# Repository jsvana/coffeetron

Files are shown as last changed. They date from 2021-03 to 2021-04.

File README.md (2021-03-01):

# coffeetron - WIP

Arduino sketch to pour a shot of espresso in a [Gaggia Classic Pro](https://www.gaggia.com/manual-machines/new-classic/) to a specific weight.

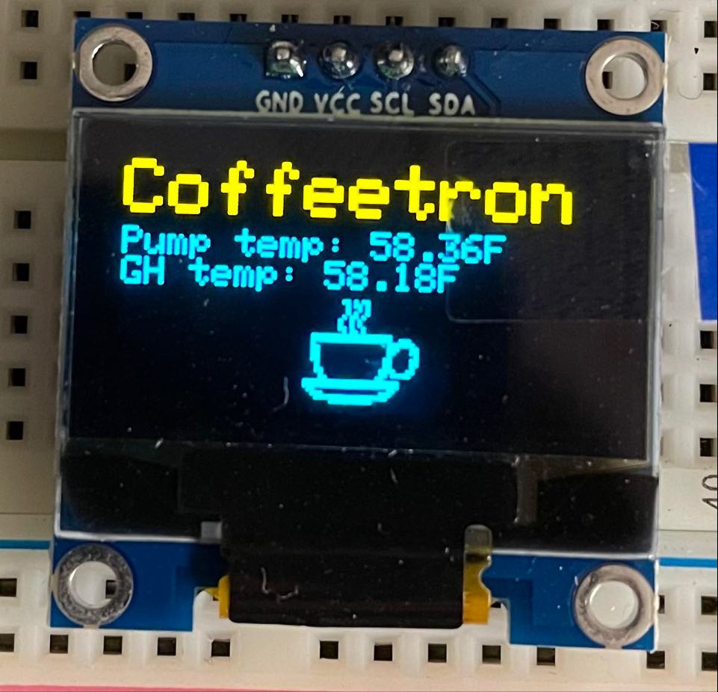
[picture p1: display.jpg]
Coffeetron display


Fun side project. Probably does things wrong, and isn't really useful unless you have the same setup I do. Feel free to use as a reference if you want!

## Pump control

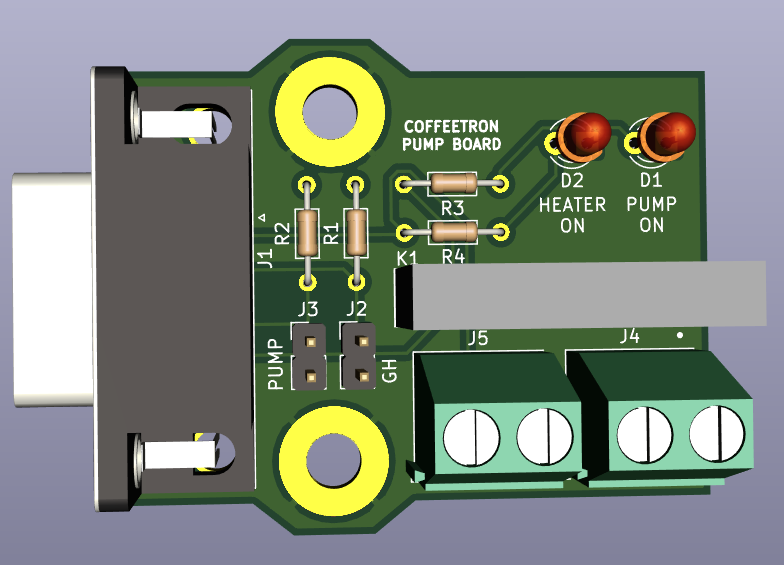
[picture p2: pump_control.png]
Pump control PCB


## License

[MIT](LICENSE.md)

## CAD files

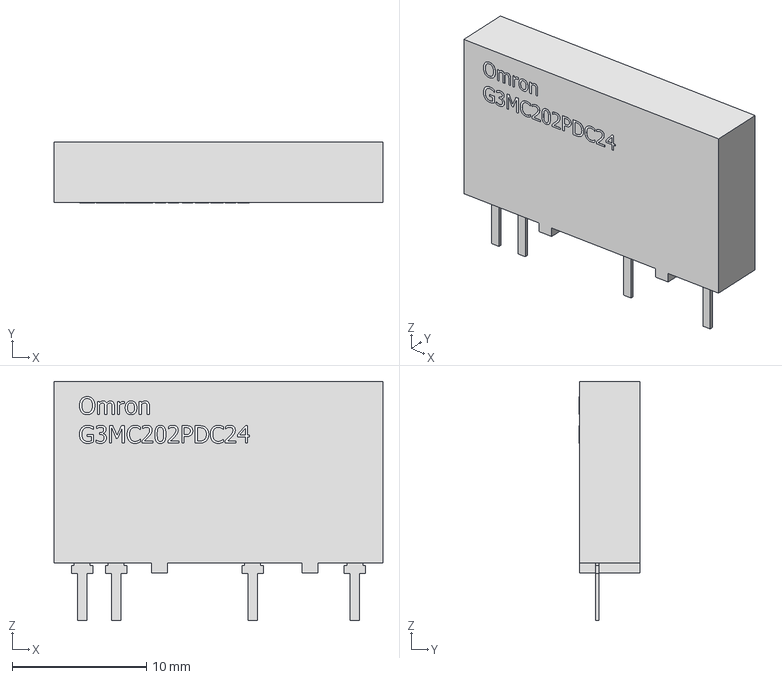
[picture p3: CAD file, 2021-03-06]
hardware/pump/eec.models/Omron_-_G3MC202PDC24.step
24.5 x 4.51 x 17.8 mm

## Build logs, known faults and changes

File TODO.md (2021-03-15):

# TODO

## Software
- [x] Flush
- [x] Preinfusion
- [ ] "Needs flush" warning after brew
- [x] Configurable targets
  - [x] Configurable output weight
  - [x] Configurable preinfusion enable
  - [x] Configurable preinfusion pump time
  - [x] Configurable preinfusion wait time
  - [x] Configurable brew temperature
  - [x] Minimum values on configuration selectors
- [ ] Stat output
- [ ] Fix screen corruption

## Head unit
- [x] Screen
- [x] Configurable value entry
- [x] Configurable entry selector button
- [x] Start button
- [x] Flush button
- [x] Brew stats button
- [ ] USB mount?
- [ ] On switch
- [ ] Reservoir level sensor
- [ ] Drip tray fill sensor
- [ ] PCB designed

## Pump controller
- [x] Grouphead temperature
- [x] Pump relay
- [x] Heater PID controller (~11A)
- [ ] Pump thermocouple
- [x] PCB designed

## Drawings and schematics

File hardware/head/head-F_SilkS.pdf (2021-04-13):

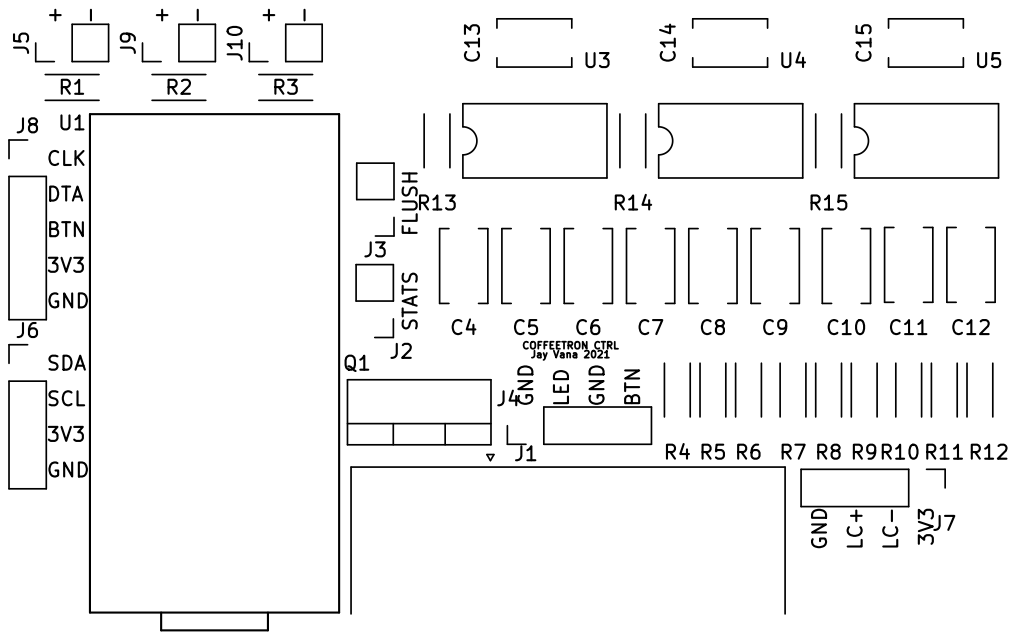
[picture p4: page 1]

- GND LED GND BTNSDA

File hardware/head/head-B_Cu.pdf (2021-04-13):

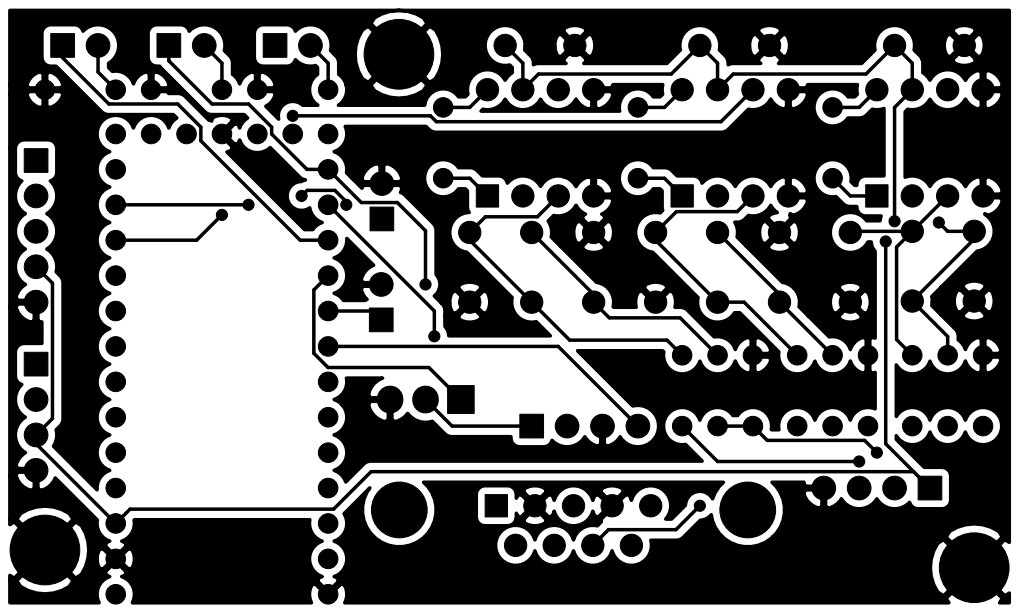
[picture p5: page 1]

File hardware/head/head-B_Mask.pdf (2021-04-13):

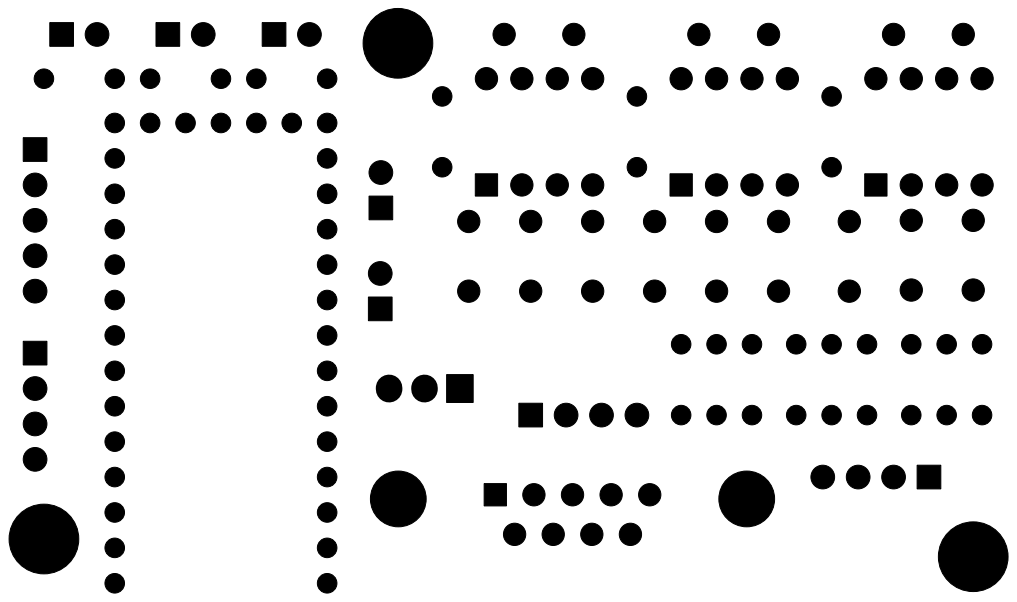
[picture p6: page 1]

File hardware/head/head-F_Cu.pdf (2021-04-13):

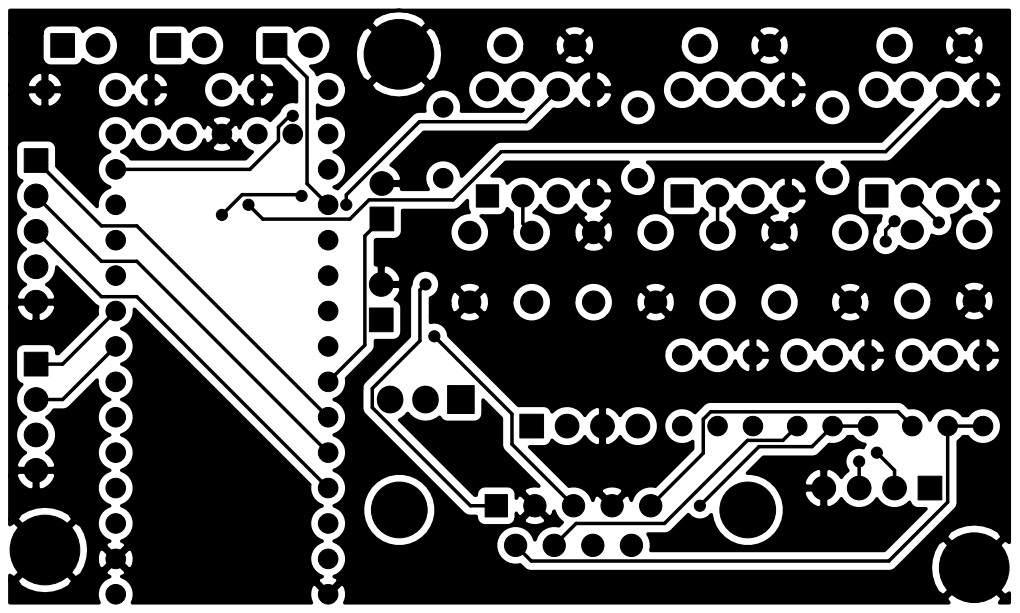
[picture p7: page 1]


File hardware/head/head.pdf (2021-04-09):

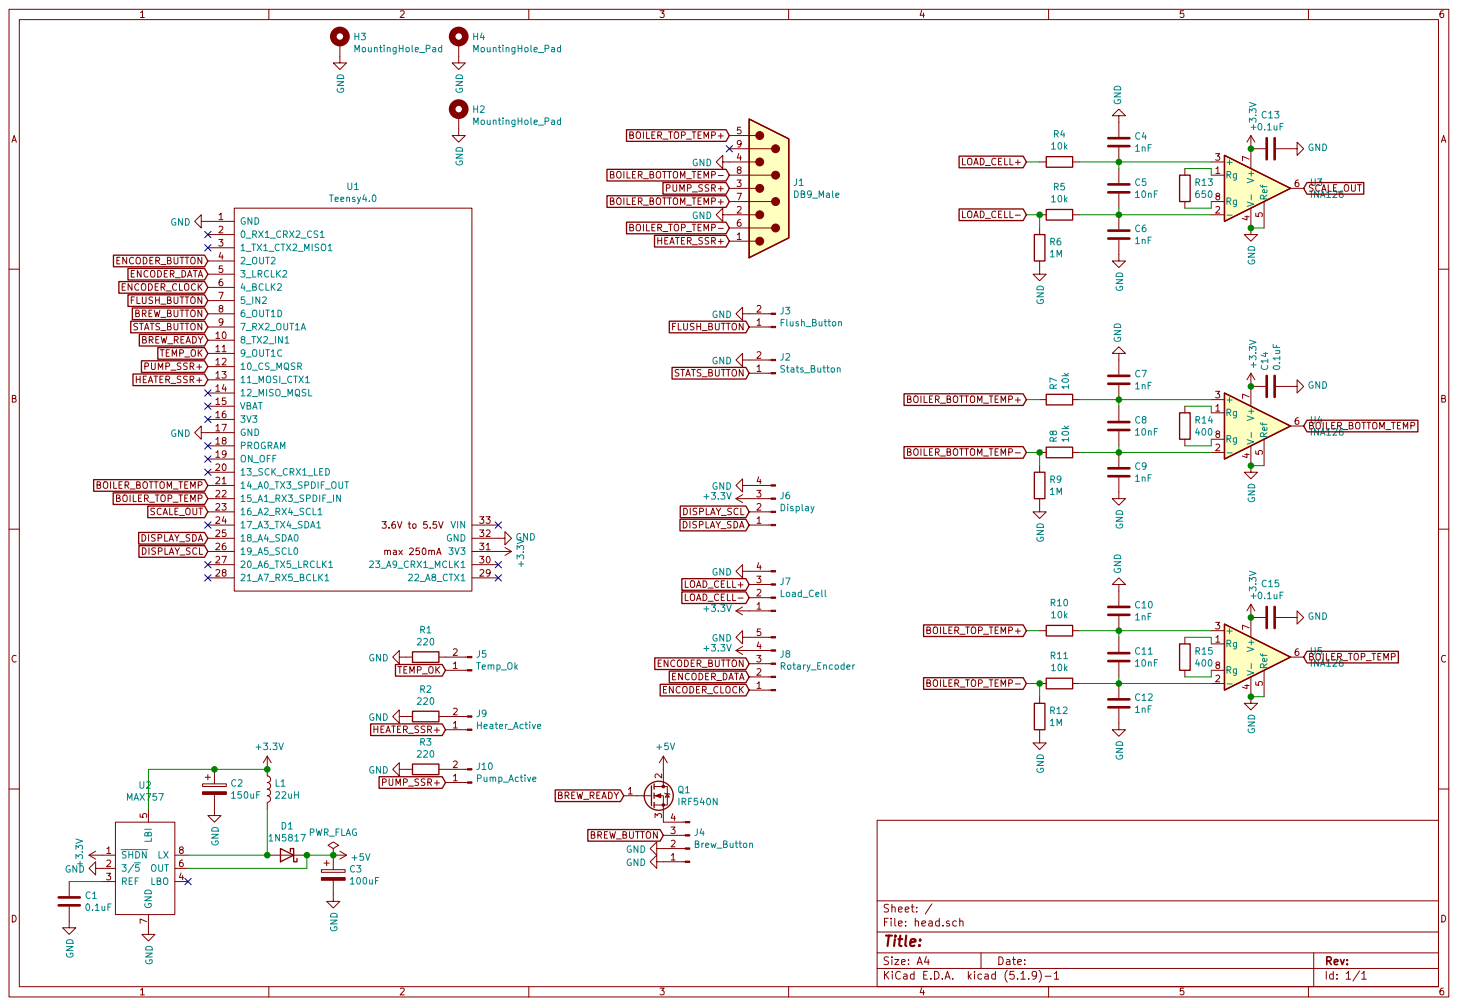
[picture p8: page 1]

Id: 1/1 Title: File: head.sch Sheet: /

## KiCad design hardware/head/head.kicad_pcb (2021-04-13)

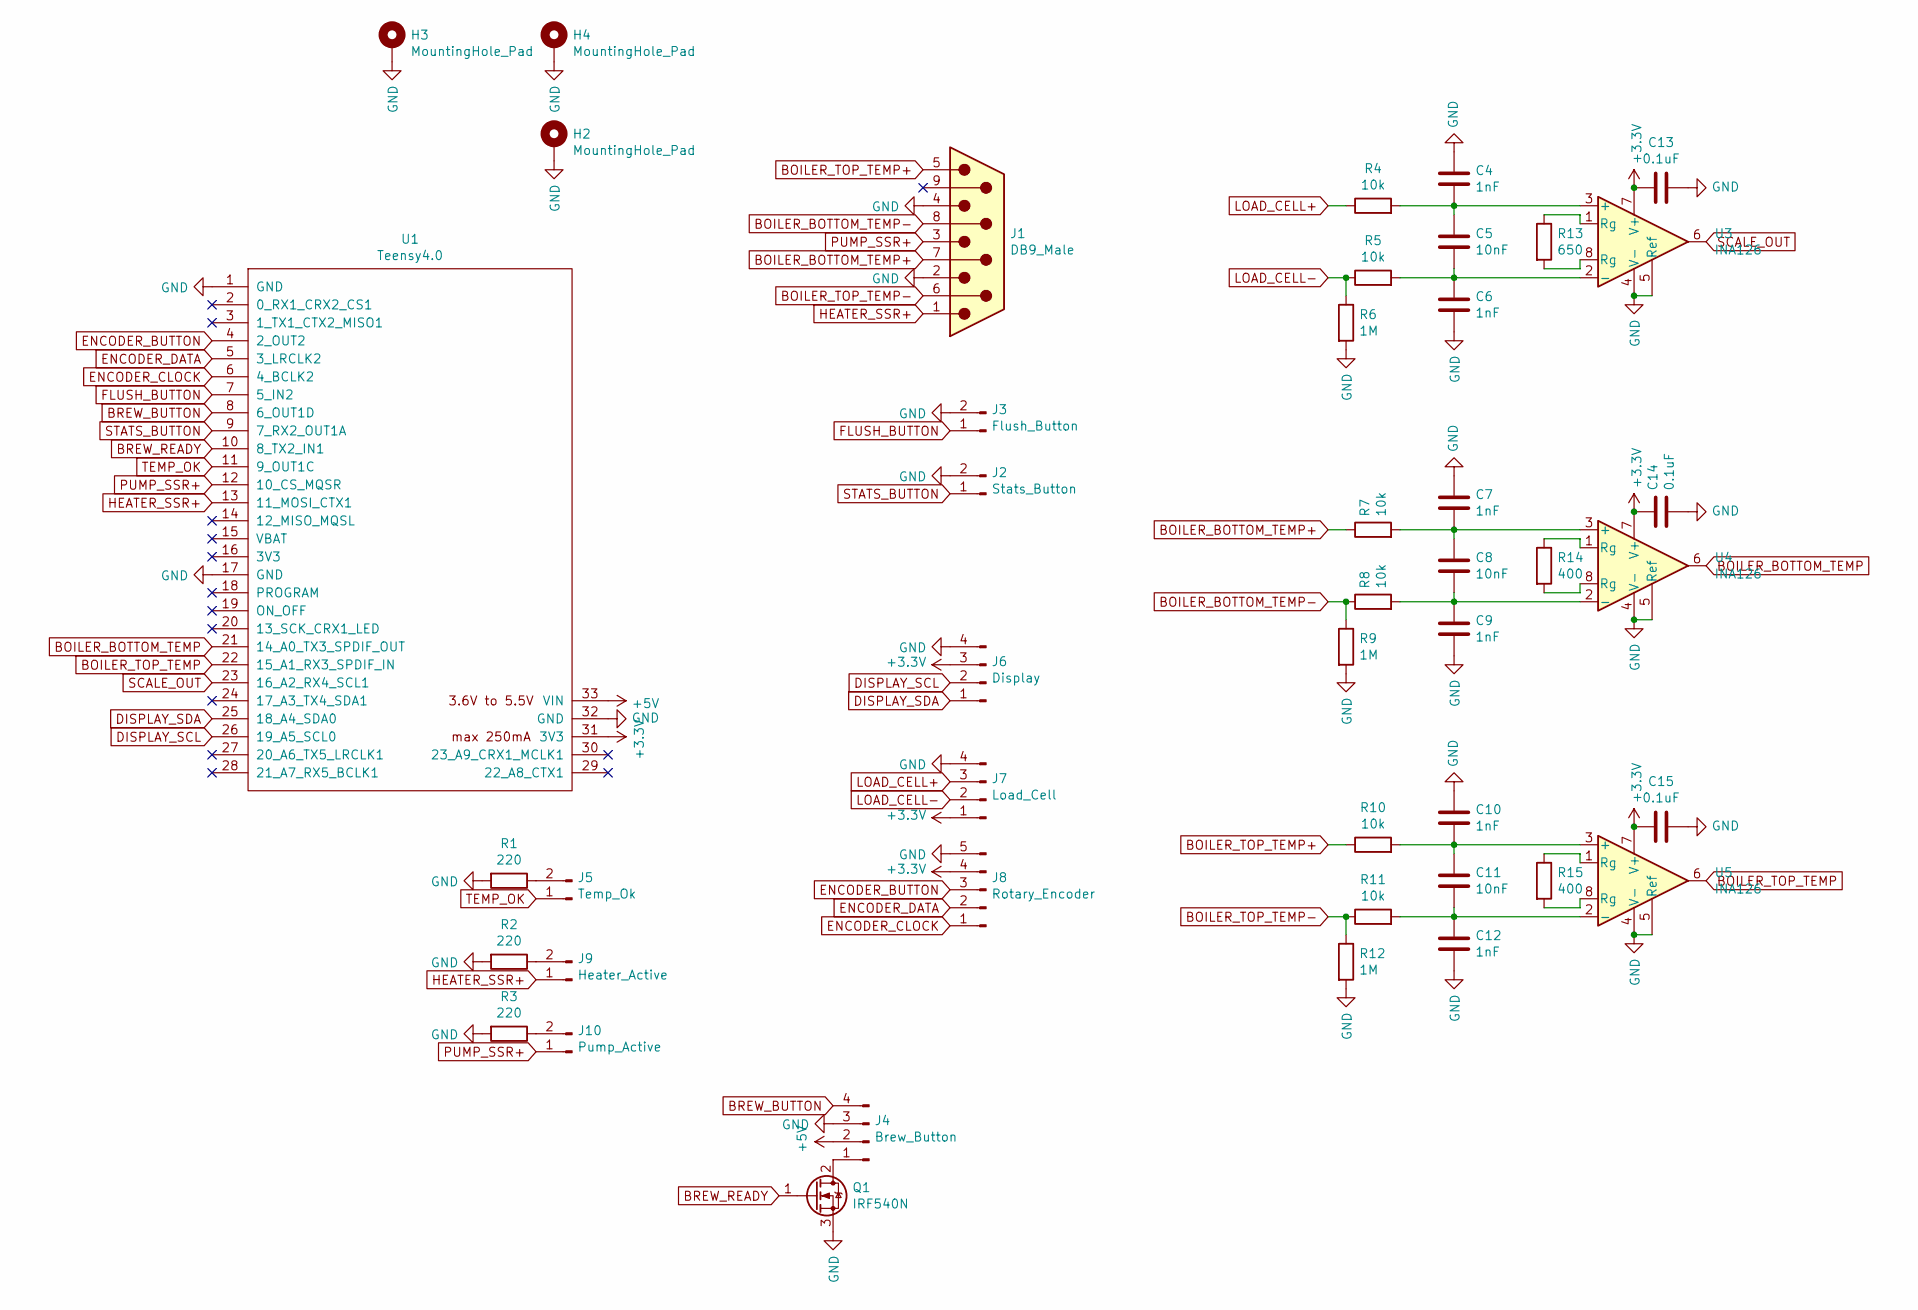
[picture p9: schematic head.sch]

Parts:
C4, C6, C7, C9, C10, C12: 1nF; C_Disc_D5.1mm_W3.2mm_P5.00mm
C5, C8, C11: 10nF; C_Disc_D5.1mm_W3.2mm_P5.00mm
C13, C14, C15: 0.1uF; C_Disc_D5.1mm_W3.2mm_P5.00mm
H2, H3, H4: MountingHole_Pad; MountingHole_2.5mm_Pad
J1: DB9_Male; DSUB-9_Male_Horizontal_P2.77x2.84mm_EdgePinOffset4.94mm_Hou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
J2: Stats_Button; PinHeader_1x02_P2.54mm_Vertical
J3: Flush_Button; PinHeader_1x02_P2.54mm_Vertical
J4: Brew_Button; PinHeader_1x04_P2.54mm_Vertical
J5: Temp_Ok; PinHeader_1x02_P2.54mm_Vertical
J6: Display; PinHeader_1x04_P2.54mm_Vertical
J7: Load_Cell; PinHeader_1x04_P2.54mm_Vertical
J8: Rotary_Encoder; PinHeader_1x05_P2.54mm_Vertical
J9: Heater_Active; PinHeader_1x02_P2.54mm_Vertical
J10: Pump_Active; PinHeader_1x02_P2.54mm_Vertical
Q1: IRF540N; TO-220-3_Vertical
R1, R2, R3: 220; R_Axial_DIN0204_L3.6mm_D1.6mm_P5.08mm_Horizontal
R4, R5, R7, R8, R10, R11: 10k; R_Axial_DIN0204_L3.6mm_D1.6mm_P5.08mm_Horizontal
R6, R9, R12: 1M; R_Axial_DIN0204_L3.6mm_D1.6mm_P5.08mm_Horizontal
R13: 650; R_Axial_DIN0204_L3.6mm_D1.6mm_P5.08mm_Horizontal
R14, R15: 400; R_Axial_DIN0204_L3.6mm_D1.6mm_P5.08mm_Horizontal
U1: Teensy4.0; Teensy40_SMT
U3, U4, U5: INA126; DIP-8_W7.62mm

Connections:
+3V3: C13.1, C14.1, C15.1, J6.3, J7.1, J8.4, U1.31 (3V3), U3.7 (V+), U4.7 (V+), U5.7 (V+)
+5V: J4.2, U1.33 (VIN)
BOILER_BOTTOM_TEMP: U1.21 (14_A0_TX3_SPDIF_OUT), U4.6
BOILER_BOTTOM_TEMP+: J1.7, R7.1
BOILER_BOTTOM_TEMP-: J1.8, R8.1, R9.1
BOILER_TOP_TEMP: U1.22 (15_A1_RX3_SPDIF_IN), U5.6
BOILER_TOP_TEMP+: J1.5, R10.1
BOILER_TOP_TEMP-: J1.6, R11.1, R12.1
BREW_BUTTON: J4.4, U1.8 (6_OUT1D)
BREW_READY: Q1.1 (G), U1.10 (8_TX2_IN1)
DISPLAY_SCL: J6.2, U1.26 (19_A5_SCL0)
DISPLAY_SDA: J6.1, U1.25 (18_A4_SDA0)
ENCODER_BUTTON: J8.3, U1.4 (2_OUT2)
ENCODER_CLOCK: J8.1, U1.6 (4_BCLK2)
ENCODER_DATA: J8.2, U1.5 (3_LRCLK2)
FLUSH_BUTTON: J3.1, U1.7 (5_IN2)
GND: C4.1, C6.2, C7.1, C9.2, C10.1, C12.2, C13.2, C14.2, C15.2, H2.1, H3.1, H4.1, J1.2, J1.4, J2.2, J3.2, J4.3, J6.4, J7.4, J8.5, Q1.3 (S), R1.2, R2.2, R3.2, R6.2, R9.2, R12.2, U1.1 (GND), U1.17 (GND), U1.32 (GND), U3.4 (V-), U3.5 (Ref), U4.4 (V-), U4.5 (Ref), U5.4 (V-), U5.5 (Ref)
HEATER_SSR+: J1.1, J9.1, U1.13 (11_MOSI_CTX1)
LOAD_CELL+: J7.3, R4.1
LOAD_CELL-: J7.2, R5.1, R6.1
unnamed: C4.2, C5.1, R4.2, U3.3 (+)
unnamed: C5.2, C6.1, R5.2, U3.2 (-)
unnamed: C7.2, C8.1, R7.2, U4.3 (+)
unnamed: C8.2, C9.1, R8.2, U4.2 (-)
unnamed: C10.2, C11.1, R10.2, U5.3 (+)
unnamed: C11.2, C12.1, R11.2, U5.2 (-)
unnamed: J4.1, Q1.2 (D)
unnamed: J5.2, R1.1
unnamed: J9.2, R2.1
unnamed: J10.2, R3.1
unnamed: R13.1, U3.1 (Rg)
unnamed: R13.2, U3.8 (Rg)
unnamed: R14.1, U4.1 (Rg)
unnamed: R14.2, U4.8 (Rg)
unnamed: R15.1, U5.1 (Rg)
unnamed: R15.2, U5.8 (Rg)
PUMP_SSR+: J1.3, J10.1, U1.12 (10_CS_MQSR)
SCALE_OUT: U1.23 (16_A2_RX4_SCL1), U3.6
STATS_BUTTON: J2.1, U1.9 (7_RX2_OUT1A)
TEMP_OK: J5.1, U1.11 (9_OUT1C)

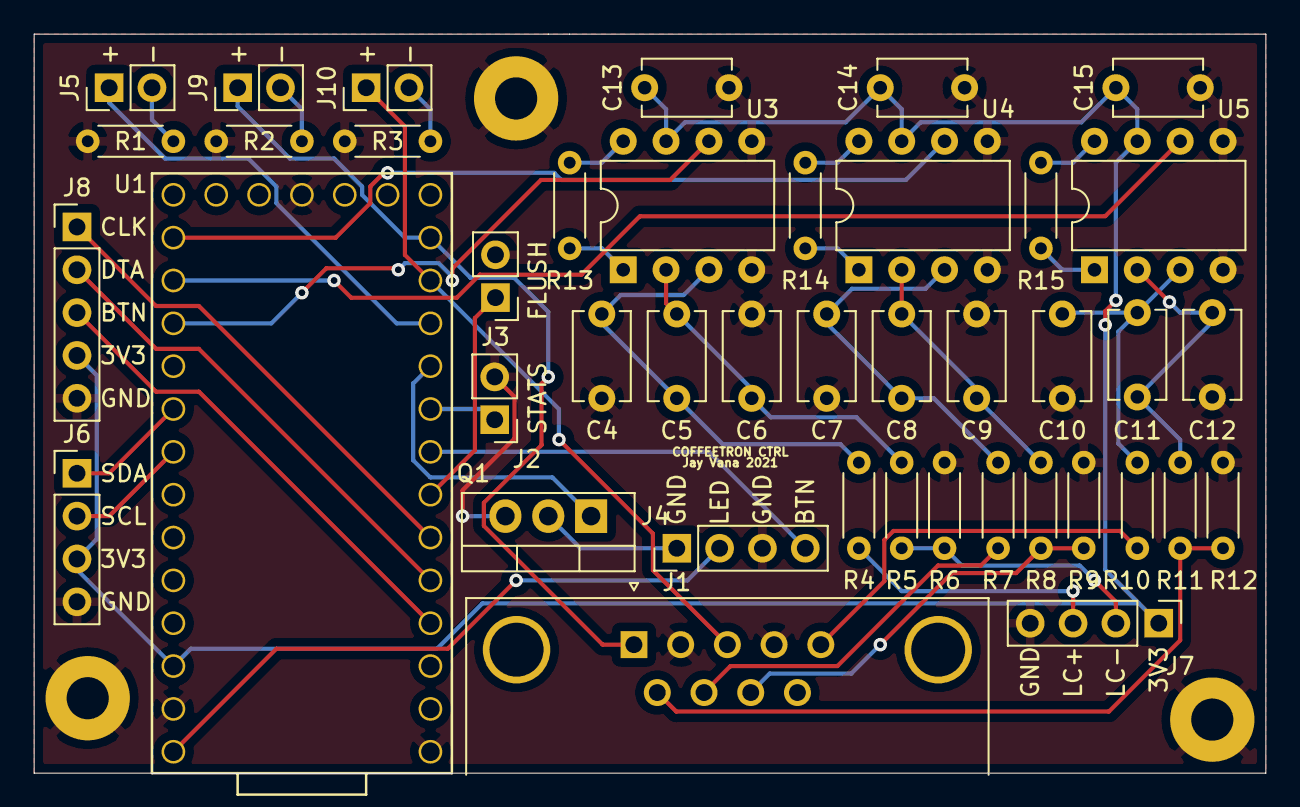
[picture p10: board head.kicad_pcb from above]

Board: 2 copper layers, 73.0 x 43.8 mm, 45 parts (0 on the bottom side), 40 nets.

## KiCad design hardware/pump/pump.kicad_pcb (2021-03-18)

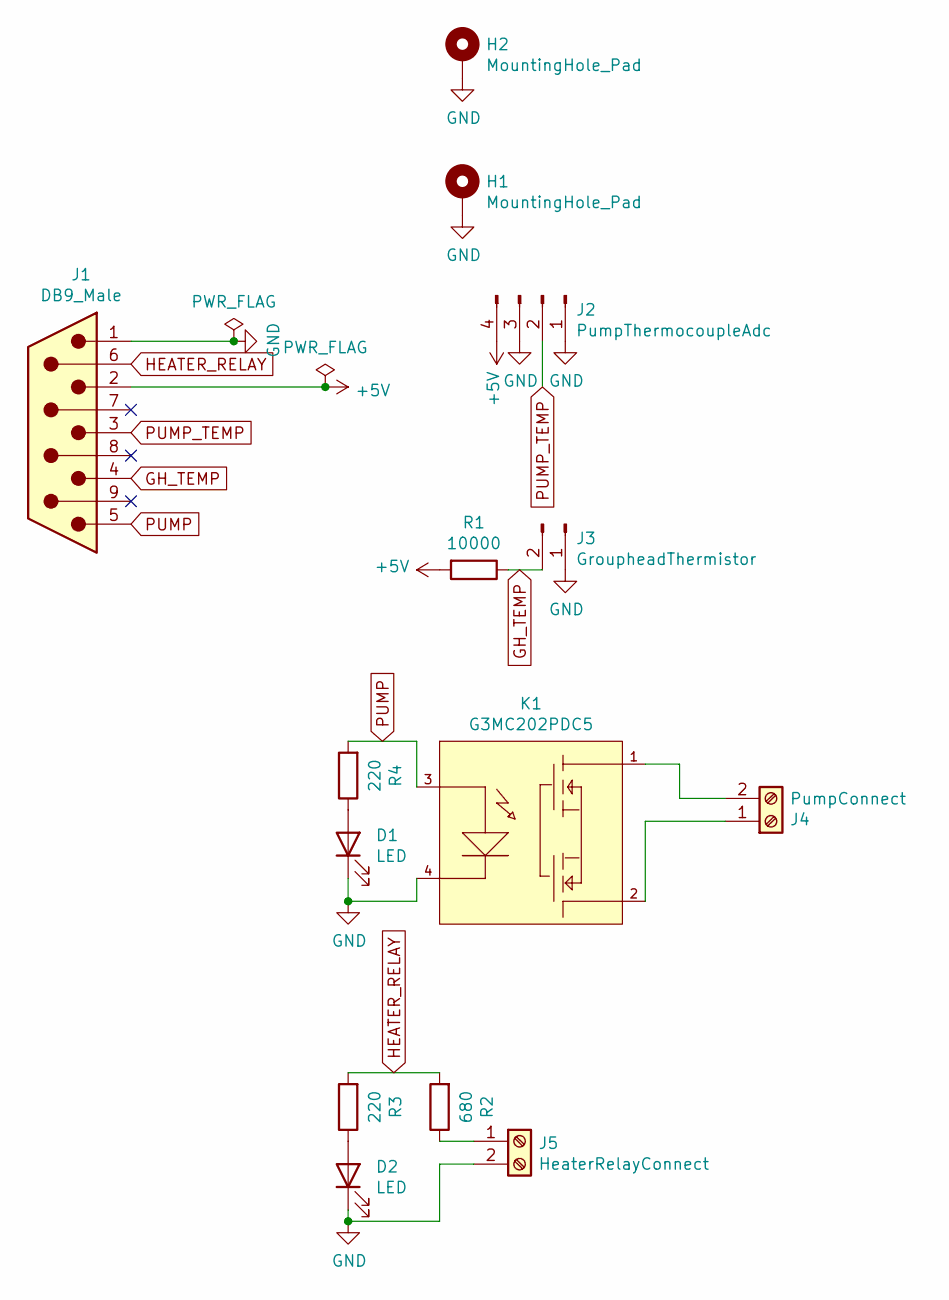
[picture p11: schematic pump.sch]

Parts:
D1, D2: LED; LED_D3.0mm
H1, H2: MountingHole_Pad; MountingHole_4.3mm_M4_Pad
J1: DB9_Male; DSUB-9_Male_Horizontal_P2.77x2.84mm_EdgePinOffset4.94mm_Hou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
J2: PumpThermocoupleAdc; PinHeader_1x04_P2.54mm_Vertical
J3: GroupheadThermistor; PinHeader_1x02_P2.54mm_Vertical
J4: PumpConnect; TerminalBlock_Phoenix_MKDS-1,5-2-5.08_1x02_P5.08mm_Horizont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
J5: HeaterRelayConnect; TerminalBlock_Phoenix_MKDS-1,5-2-5.08_1x02_P5.08mm_Horizont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
K1: G3MC202PDC5; Omron-G3MC202PDC5-0-0-0; output voltage 1.6V; voltage rating AC 100-240V; mouser part number 653-G3MC-202P-DC5; digikey description RELAY SSR SPST-NO SIP 5VDC
R1: 10000; R_Axial_DIN0204_L3.6mm_D1.6mm_P7.62mm_Horizontal
R2: 680; R_Axial_DIN0204_L3.6mm_D1.6mm_P7.62mm_Horizontal
R3, R4: 220; R_Axial_DIN0204_L3.6mm_D1.6mm_P7.62mm_Horizontal

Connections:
+5V: J1.2, J2.4, R1.2
GH_TEMP: J1.4, J3.2, R1.1
GND: D1.1 (K), D2.1 (K), H1.1, H2.1, J1.1, J2.1, J2.3, J3.1, J5.2, K1.4 (-)
HEATER_RELAY: J1.6, R2.2, R3.2
unnamed: D1.2 (A), R4.1
unnamed: D2.2 (A), R3.1
unnamed: J4.1, K1.2
unnamed: J4.2, K1.1
unnamed: J5.1, R2.1
PUMP: J1.5, K1.3 (+), R4.2
PUMP_TEMP: J1.3, J2.2

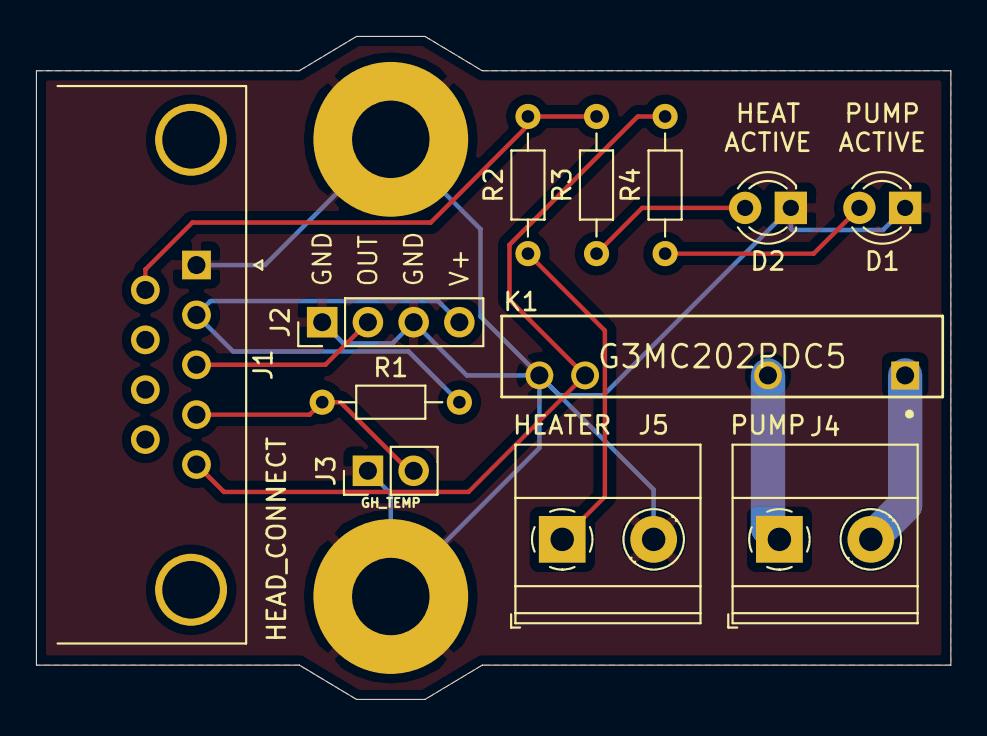
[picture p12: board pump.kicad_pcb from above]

Board: 2 copper layers, 50.8 x 36.8 mm, 14 parts (0 on the bottom side), 11 nets.

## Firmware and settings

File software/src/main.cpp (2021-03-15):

#include <Arduino.h>

#include <Adafruit_I2CDevice.h>
#include <Adafruit_SSD1306.h>
#include <ArduinoJson.h>
#include <Bounce2.h>
#include <Encoder.h>
#include <HX711.h>
#include <PID_v2.h>
#include <SPI.h>
#include <Wire.h>

#include "constants.h"
#include "util.h"

Adafruit_SSD1306 display(128, 64, &Wire, -1);
HX711 scale;

// Calibrated to my specific scale, YMMV
float calibration_factor = 416.0;

int desired_weight_in_grams;
int desired_pump_temperature;
// TODO: handle underflow
unsigned long desired_preinfuse_pump_time_in_milliseconds;
unsigned long desired_preinfuse_wait_time_in_milliseconds;

bool preinfusion_enabled;

unsigned long state_start_millis = 0;

unsigned long heater_window_start = 0;
unsigned short last_report_window = 0;
unsigned short last_brew_report_window = 0;

bool has_most_recent_pour = false;
unsigned short last_pour_seconds;
float last_pour_weight;

Encoder encoder(3, 4);
Bounce brew_button;
Bounce flush_button;
Bounce encoder_button;
Bounce stats_button;

PID_v2 heater_pid(PID_KP, PID_KI, PID_KD, PID::Direct);

DynamicJsonDocument doc(1024);

enum State {
  Waiting,

  ConfigurePumpTemp,
  ConfigureWeight,
  ConfigurePreinfuseEnabled,
  ConfigurePreinfusePumpTime,
  ConfigurePreinfuseWaitTime,

  Preinfusing,
  WaitingAfterPreinfusing,
  Brewing,

  Flushing,

  BrewStats,

  Error,
};

State current_state;

Temps<5, A0, A1> temps;

State (*tick_func)();

void set_temp_led(float reading) {
  if (abs(reading - desired_pump_temperature) < ACCEPTABLE_TEMP_ERROR) {
    digitalWrite(TEMP_OK_LED, HIGH);
  } else {
    digitalWrite(TEMP_OK_LED, LOW);
  }
}

void display_temps() {
  display.setTextSize(1);

  display.print(F("Pump temp: "));
  const auto pump_reading = temps.average_pump_temperature();
  if (pump_reading.is_error()) {
    display.println(F("ERR"));
  } else {
    display.print(pump_reading.reading());
    display.println(F("F"));
  }
  display.print(F("GH temp: "));
  const auto grouphead_reading = temps.average_grouphead_temperature();
  if (grouphead_reading.is_error()) {
    display.println(F("ERR"));
  } else {
    display.print(grouphead_reading.reading());
    display.println(F("F"));
  }
}

void display_coffee_image() {
  display.drawBitmap(0, 32, coffee_bitmap, 128, 32, WHITE);
}

void send_preinfusion_start_event() {
  doc.clear();

  doc["type"] = "event";
  doc["event"] = "preinfusion_start";
  serializeJson(doc, Serial);
  Serial.println();
}

void send_preinfusion_done_event() {
  doc.clear();

  doc["type"] = "event";
  doc["event"] = "preinfusion_end";
  serializeJson(doc, Serial);
  Serial.println();
}

void send_brew_start_event() {
  doc.clear();

  doc["type"] = "event";
  doc["event"] = "brew_start";
  serializeJson(doc, Serial);
  Serial.println();
}

void send_brew_done_event() {
  doc.clear();

  doc["type"] = "event";
  doc["event"] = "brew_end";
  doc["total_seconds"] = last_pour_seconds;
  doc["total_weight"] = last_pour_weight;
  doc["preinfusion_pump_time_millis"] =
      desired_preinfuse_pump_time_in_milliseconds;
  doc["preinfusion_wait_time_millis"] =
      desired_preinfuse_wait_time_in_milliseconds;
  serializeJson(doc, Serial);
  Serial.println();
}

void send_flush_start_event() {
  doc.clear();

  doc["type"] = "event";
  doc["event"] = "flush_start";
  serializeJson(doc, Serial);
  Serial.println();
}

void send_flush_done_event() {
  doc.clear();

  doc["type"] = "event";
  doc["event"] = "flush_end";
  serializeJson(doc, Serial);
  Serial.println();
}

State waiting_tick() {
  brew_button.update();
  flush_button.update();
  encoder_button.update();
  stats_button.update();

  State next_state;
  if (brew_button.fell()) {
    scale.tare();

    if (preinfusion_enabled) {
      next_state = State::Preinfusing;
      send_preinfusion_start_event();
    } else {
      next_state = State::Brewing;
      send_brew_start_event();
    }
  } else if (flush_button.fell()) {
    next_state = State::Flushing;
    send_flush_start_event();
  } else if (encoder_button.fell()) {
    encoder.write(desired_pump_temperature * 4);
    next_state = State::ConfigurePumpTemp;
  } else if (stats_button.fell()) {
    next_state = State::BrewStats;
  } else {
    next_state = State::Waiting;
  }

  pump_off();

  display.setTextSize(2);

  display.println(F("Coffeetron"));

  display_temps();

  display_coffee_image();

  return next_state;
}

State configure_pump_temp_tick() {
  desired_pump_temperature = encoder.read() / 4;

  heater_pid.Setpoint(desired_pump_temperature);

  if (desired_pump_temperature < 1) {
    desired_pump_temperature = 1;
    encoder.write(4);
  }

  encoder_button.update();

  State next_state;
  if (encoder_button.fell()) {
    encoder.write(desired_weight_in_grams * 4);
    next_state = State::ConfigureWeight;
  } else {
    next_state = State::ConfigurePumpTemp;
  }

  pump_off();

  display.setTextSize(1);

  display.println(F("Set target pump temp"));

  display.print(desired_pump_temperature);
  display.println(F(" degF"));

  display_coffee_image();

  return next_state;
}

State configure_weight_tick() {
  desired_weight_in_grams = encoder.read() / 4;

  if (desired_weight_in_grams < 1) {
    desired_weight_in_grams = 1;
    encoder.write(4);
  }

  encoder_button.update();

  State next_state;
  if (encoder_button.fell()) {
    encoder.write(preinfusion_enabled ? 4 : 0);
    next_state = State::ConfigurePreinfuseEnabled;
  } else {
    next_state = State::ConfigureWeight;
  }

  pump_off();

  display.setTextSize(1);

  display.println(F("Set target weight"));

  display.print(desired_weight_in_grams);
  display.println(F("g"));

  display_coffee_image();

  return next_state;
}

State configure_preinfuse_enabled_tick() {
  auto encoder_value = encoder.read() / 4;

  if (encoder_value < 0) {
    encoder_value = 1;
    encoder.write(4);
  }

  preinfusion_enabled = encoder_value % 2 == 1;

  encoder_button.update();

  State next_state;
  if (encoder_button.fell()) {
    if (preinfusion_enabled) {
      encoder.write(desired_preinfuse_pump_time_in_milliseconds * 4 / 1000);
      next_state = State::ConfigurePreinfusePumpTime;
    } else {
      next_state = State::Waiting;
    }
  } else {
    next_state = State::ConfigurePreinfuseEnabled;
  }

  pump_off();

  display.setTextSize(1);

  display.println(F("Enable preinfusion?"));

  display.print(preinfusion_enabled ? "yes" : "no");

  display_coffee_image();

  return next_state;
}

State configure_preinfuse_pump_time_tick() {
  auto encoder_value = encoder.read() / 4;

  if (encoder_value < 0) {
    encoder_value = 0;
    encoder.write(0);
  }

  desired_preinfuse_pump_time_in_milliseconds = encoder_value * 1000;

  encoder_button.update();

  State next_state;
  if (encoder_button.fell()) {
    encoder.write(desired_preinfuse_wait_time_in_milliseconds * 4 / 1000);
    next_state = State::ConfigurePreinfuseWaitTime;
  } else {
    next_state = State::ConfigurePreinfusePumpTime;
  }

  pump_off();

  display.setTextSize(1);

  display.println(F("Set preinfuse pump time"));

  display.print(desired_preinfuse_pump_time_in_milliseconds / 1000);
  display.println(F("s"));

  display_coffee_image();

  return next_state;
}

State configure_preinfuse_wait_time_tick() {
  auto encoder_value = encoder.read() / 4;

  if (encoder_value < 0) {
    encoder_value = 0;
    encoder.write(0);
  }

  desired_preinfuse_wait_time_in_milliseconds = encoder_value * 1000;

  encoder_button.update();

  State next_state;
  if (encoder_button.fell()) {
    next_state = State::Waiting;
  } else {
    next_state = State::ConfigurePreinfuseWaitTime;
  }

  pump_off();

  display.setTextSize(1);

  display.println(F("Set preinfuse wait time"));

  display.print(desired_preinfuse_wait_time_in_milliseconds / 1000);
  display.println(F("s"));

  display_coffee_image();

  return next_state;
}

State preinfusing_tick() {
  const auto now = millis();

  State next_state;
  if (now - state_start_millis > desired_preinfuse_pump_time_in_milliseconds) {
    next_state = State::WaitingAfterPreinfusing;
    send_preinfusion_done_event();
  } else {
    next_state = State::Preinfusing;
  }

  pump_on();

  display.setTextSize(2);

  display.println(F("Infusing"));

  display.setTextSize(1);

  display.println(F("Pumping"));
  display.print((state_start_millis +
                 desired_preinfuse_pump_time_in_milliseconds - now + 500) /
                1000);
  display.println(F("s remaining"));

  display.println(F(""));

  display_temps();

  return next_state;
}

State waiting_after_preinfusing_tick() {
  const auto now = millis();

  State next_state;
  if (now - state_start_millis > desired_preinfuse_wait_time_in_milliseconds) {
    next_state = State::Brewing;
    send_brew_start_event();
  } else {
    next_state = State::WaitingAfterPreinfusing;
  }

  pump_off();

  display.setTextSize(2);

  display.println(F("Infusing"));

  display.setTextSize(1);

  display.println(F("Waiting"));
  display.print((state_start_millis +
                 desired_preinfuse_wait_time_in_milliseconds - now + 500) /
                1000);
  display.println(F("s remaining"));

  display.println(F(""));

  display_temps();

  return next_state;
}

State brewing_tick() {
  const auto now = millis();

  // Note that this is very slow
  const auto weight = scale.get_units();

  const unsigned short current_brew_report_window = now / 1000;
  if (current_brew_report_window != last_brew_report_window) {
    last_brew_report_window = current_brew_report_window;
    doc.clear();

    doc["type"] = "brew";
    doc["weight"] = weight;
    doc["target_weight"] = desired_weight_in_grams;
    serializeJson(doc, Serial);
    Serial.println();
  }

  State next_state;

  if (weight > desired_weight_in_grams) {
    scale.tare();

    last_pour_seconds = (now - state_start_millis) / 1000;
    last_pour_weight = weight;

    has_most_recent_pour = true;

    send_brew_done_event();

    next_state = State::Waiting;
  } else {
    next_state = State::Brewing;
  }

  pump_on();

  display.setTextSize(2);

  display.println(F("Brewing..."));

  display.setTextSize(1);

  display.print(F("Target weight: "));
  display.print(desired_weight_in_grams);
  display.println(F("g"));

  display.print(F("Weight: "));
  display.print(weight);
  display.println(F("g"));

  display.print(F("Elapsed: "));
  display.print((now - state_start_millis) / 1000);
  display.println(F("s"));

  display_temps();

  return next_state;
}

State flushing_tick() {
  State next_state;
  if (millis() - state_start_millis > FLUSH_TIME_MILLIS) {
    send_flush_done_event();

    next_state = State::Waiting;
  } else {
    next_state = State::Flushing;
  }

  pump_on();

  display.setTextSize(2);

  display.println(F("Flushing"));

  display.setTextSize(1);

  display_temps();

  display_coffee_image();

  return next_state;
}

State brew_stats_tick() {
  stats_button.update();

  State next_state;
  if (stats_button.fell()) {
    next_state = State::Waiting;
  } else {
    next_state = State::BrewStats;
  }

  pump_off();

  display.setTextSize(1);

  display.println(F("Brew stats"));

  if (has_most_recent_pour) {
    display.println(F("Most recent pour:"));
    display.print(F(" Total time: "));
    display.print(last_pour_seconds);
    display.println(F("s"));
    display.print(F(" Total weight: "));
    display.print(last_pour_weight);
    display.println(F("g"));
  } else {
    display.println(F("No pour found"));
  }

  display_coffee_image();

  return next_state;
}

State error_tick() {
  display.setTextSize(2);

  display.println(F("ERROR"));

  display.setTextSize(1);
  display.print(F("Unknown state \""));
  display.print(current_state);
  display.println(F("\""));

  return State::Error;
}

void set_new_state(const State &state) {
  state_start_millis = millis();
  current_state = state;

  switch (state) {
  case State::Waiting:
    tick_func = &waiting_tick;
    break;

  case State::ConfigurePumpTemp:
    tick_func = &configure_pump_temp_tick;
    break;

  case State::ConfigureWeight:
    tick_func = &configure_weight_tick;
    break;

  case State::ConfigurePreinfuseEnabled:
    tick_func = &configure_preinfuse_enabled_tick;
    break;

  case State::ConfigurePreinfusePumpTime:
    tick_func = &configure_preinfuse_pump_time_tick;
    break;

  case State::ConfigurePreinfuseWaitTime:
    tick_func = &configure_preinfuse_wait_time_tick;
    break;

  case State::Flushing:
    tick_func = &flushing_tick;
    break;

  case State::Preinfusing:
    tick_func = &preinfusing_tick;
    break;

  case State::WaitingAfterPreinfusing:
    tick_func = &waiting_after_preinfusing_tick;
    break;

  case State::Brewing:
    tick_func = &brewing_tick;
    break;

  case State::BrewStats:
    tick_func = &brew_stats_tick;
    break;

  case State::Error:
  default:
    tick_func = &error_tick;
    break;
  }
}

void heater_relay_off() { digitalWrite(HEATER_RELAY, LOW); }

void heater_relay_on() { digitalWrite(HEATER_RELAY, HIGH); }

void setup() {
  pinMode(TEMP_OK_LED, OUTPUT);

  Serial.begin(9600);
  if (!display.begin(SSD1306_SWITCHCAPVCC, 0x3C)) {
    Serial.println(F("failed to initialize OLED display"));
    digitalWrite(TEMP_OK_LED, HIGH);
    for (;;)
      ; // Don't proceed, loop forever
  }

  scale.begin(HX711_DOUT, HX711_CLK);
  scale.set_scale(calibration_factor);
  scale.tare();
  digitalWrite(TEMP_OK_LED, HIGH);

  encoder_button.attach(2, INPUT_PULLUP);
  encoder_button.interval(25);

  flush_button.attach(7, INPUT_PULLUP);
  flush_button.interval(25);

  brew_button.attach(8, INPUT_PULLUP);
  brew_button.interval(25);

  stats_button.attach(9, INPUT_PULLUP);
  stats_button.interval(25);

  // blue white == A0 == pump temp
  // blue == A1 == grouphead temp
  // brown white == GND
  // brown == VCC
  // orange white == pump relay

  pinMode(PUMP, OUTPUT);
  pinMode(HEATER_RELAY, OUTPUT);
  // pinMode(TEMP_OK_LED, OUTPUT);

  digitalWrite(PUMP, LOW);
  digitalWrite(HEATER_RELAY, LOW);
  // digitalWrite(TEMP_OK_LED, LOW);
  digitalWrite(TEMP_OK_LED, HIGH);

  desired_pump_temperature = INITIAL_DESIRED_PUMP_TEMPERATURE;
  desired_weight_in_grams = INITIAL_DESIRED_WEIGHT_GRAMS;
  desired_preinfuse_pump_time_in_milliseconds =
      INITIAL_DESIRED_PREINFUSE_PUMP_TIME_MILLISECONDS;
  desired_preinfuse_wait_time_in_milliseconds =
      INITIAL_DESIRED_PREINFUSE_WAIT_TIME_MILLISECONDS;

  heater_pid.SetOutputLimits(0, HEATER_PID_WINDOW_SIZE);

  while (true) {
    temps.update_samples_blocking();

    const auto reading = temps.average_pump_temperature();
    if (reading.is_error()) {
      heater_relay_off();
      continue;
    }

    heater_pid.SetOutputLimits(0, HEATER_PID_WINDOW_SIZE);
    heater_pid.Start(reading.reading(), 0, desired_pump_temperature);

    break;
  }

  preinfusion_enabled = true;

  set_new_state(State::Waiting);

  display.clearDisplay();
  display.display();
}

void control_heater_relay() {
  // Disable heater while pulling a shot
  if (current_state == State::Brewing) {
    heater_relay_off();
    return;
  }

  const auto reading = temps.average_pump_temperature();
  if (reading.is_error()) {
    heater_relay_off();
    return;
  }

  const auto temp = reading.reading();

  set_temp_led(temp);

  const auto heater_runtime = heater_pid.Run(temp);
  const auto now = millis();

  if (now - heater_window_start > HEATER_PID_WINDOW_SIZE) {
    heater_window_start += HEATER_PID_WINDOW_SIZE;
  }

  if (heater_runtime < now - heater_window_start) {
    heater_relay_off();
  } else {
    heater_relay_on();
  }
}

const __FlashStringHelper *state_as_string(const State &state) {
  switch (state) {
  case State::Waiting:
    return F("waiting");

  case State::ConfigurePumpTemp:
    return F("configure_pump_temp");

  case State::ConfigureWeight:
    return F("configure_weight");

  case State::ConfigurePreinfuseEnabled:
    return F("configure_preinfuse_enabled");

  case State::ConfigurePreinfusePumpTime:
    return F("configure_preinfuse_pump_time");

  case State::ConfigurePreinfuseWaitTime:
    return F("configure_preinfuse_wait_time");

  case State::Flushing:
    return F("flushing");

  case State::Preinfusing:
    return F("preinfusing");

  case State::WaitingAfterPreinfusing:
    return F("waiting_after_preinfusing");

  case State::Brewing:
    return F("brewing");

  case State::BrewStats:
    return F("brew_stats");

  case State::Error:
  default:
    return F("error");
  }
}

void report_stats() {
  const auto boiler_reading = temps.average_pump_temperature();
  bool boiler_temp_error = false;
  if (boiler_reading.is_error()) {
    boiler_temp_error = true;
  }

  const auto boiler_temp = boiler_reading.reading();

  const auto grouphead_reading = temps.average_grouphead_temperature();
  bool grouphead_temp_error = false;
  if (grouphead_reading.is_error()) {
    grouphead_temp_error = true;
  }

  const auto grouphead_temp = grouphead_reading.reading();

  const auto now = millis();

  const unsigned short current_report_window = now / 1000;
  if (current_report_window != last_report_window) {
    last_report_window = current_report_window;
    doc.clear();

    doc["type"] = "temp";
    doc["boiler_temp_err"] = boiler_temp_error;
    doc["boiler_temp"] = boiler_temp;
    doc["target_boiler_temp"] = desired_pump_temperature;
    doc["grouphead_temp_err"] = grouphead_temp_error;
    doc["grouphead_temp"] = grouphead_temp;
    doc["state"] = state_as_string(current_state);
    serializeJson(doc, Serial);
    Serial.println();
  }
}

void loop() {
  temps.update_samples_blocking();

  control_heater_relay();

  report_stats();

  display.clearDisplay();
  display.setCursor(0, 0);
  display.setTextColor(SSD1306_WHITE);

  State new_state = tick_func();

  if (current_state != new_state) {
    set_new_state(new_state);
  }

  display.display();
}

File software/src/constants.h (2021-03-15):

#pragma once

#define HX711_CLK 6
#define HX711_DOUT 5
#define HEATER_RELAY 10
#define PUMP 11
#define TEMP_OK_LED 12

#define SAMPLE_COUNT 5

#define VCC 5.0
#define ANALOG_MAX 1023
#define THERMISTOR_PAIRED_RESISTOR 10000.0
#define NOMINAL_RESISTANCE 10000.0
#define THERMISTOR_B_CONSTANT 3434.0
#define NOMINAL_TEMPERATURE 298.15
#define CELCIUS_OFFSET 273.15

#define MIN_TEMP_F -10.0
#define MAX_TEMP_F 350.0
#define ACCEPTABLE_TEMP_ERROR 2.0

#define FLUSH_TIME_MILLIS 1000

#define HEATER_PID_WINDOW_SIZE 100

#define INITIAL_DESIRED_PUMP_TEMPERATURE 200
#define INITIAL_DESIRED_WEIGHT_GRAMS 38
#define INITIAL_DESIRED_PREINFUSE_PUMP_TIME_MILLISECONDS 3000
#define INITIAL_DESIRED_PREINFUSE_WAIT_TIME_MILLISECONDS 7000

#define PID_KP 4.5
#define PID_KI 0.175
#define PID_KD 1.0

// Cute coffee cup bitmap to display, 128x32 pixels
const unsigned char coffee_bitmap[] PROGMEM = {
    0x00, 0x00, 0x00, 0x00, 0x00, 0x00, 0x00, 0x00, 0x00, 0x00, 0x00, 0x00,
    0x00, 0x00, 0x00, 0x00, 0x00, 0x00, 0x00, 0x00, 0x00, 0x00, 0x00, 0x00,
    0x00, 0x00, 0x00, 0x00, 0x00, 0x00, 0x00, 0x00, 0x00, 0x00, 0x00, 0x00,
    0x00, 0x00, 0x00, 0x1a, 0xc0, 0x00, 0x00, 0x00, 0x00, 0x00, 0x00, 0x00,
    0x00, 0x00, 0x00, 0x00, 0x00, 0x00, 0x00, 0x0b, 0x40, 0x00, 0x00, 0x00,
    0x00, 0x00, 0x00, 0x00, 0x00, 0x00, 0x00, 0x00, 0x00, 0x00, 0x00, 0x09,
    0x40, 0x00, 0x00, 0x00, 0x00, 0x00, 0x00, 0x00, 0x00, 0x00, 0x00, 0x00,
    0x00, 0x00, 0x00, 0x0a, 0x40, 0x00, 0x00, 0x00, 0x00, 0x00, 0x00, 0x00,
    0x00, 0x00, 0x00, 0x00, 0x00, 0x00, 0x00, 0x16, 0x80, 0x00, 0x00, 0x00,
    0x00, 0x00, 0x00, 0x00, 0x00, 0x00, 0x00, 0x00, 0x00, 0x00, 0x00, 0x25,
    0x00, 0x00, 0x00, 0x00, 0x00, 0x00, 0x00, 0x00, 0x00, 0x00, 0x00, 0x00,
    0x00, 0x00, 0x00, 0x25, 0x00, 0x00, 0x00, 0x00, 0x00, 0x00, 0x00, 0x00,
    0x00, 0x00, 0x00, 0x00, 0x00, 0x00, 0x00, 0x34, 0x80, 0x00, 0x00, 0x00,
    0x00, 0x00, 0x00, 0x00, 0x00, 0x00, 0x00, 0x00, 0x00, 0x00, 0x00, 0x16,
    0x80, 0x00, 0x00, 0x00, 0x00, 0x00, 0x00, 0x00, 0x00, 0x00, 0x00, 0x00,
    0x00, 0x00, 0x1f, 0xff, 0xff, 0x00, 0x00, 0x00, 0x00, 0x00, 0x00, 0x00,
    0x00, 0x00, 0x00, 0x00, 0x00, 0x00, 0x1f, 0xff, 0xff, 0x38, 0x00, 0x00,
    0x00, 0x00, 0x00, 0x00, 0x00, 0x00, 0x00, 0x00, 0x00, 0x00, 0x10, 0x00,
    0x01, 0xfc, 0x00, 0x00, 0x00, 0x00, 0x00, 0x00, 0x00, 0x00, 0x00, 0x00,
    0x00, 0x00, 0x18, 0x00, 0x01, 0xc6, 0x00, 0x00, 0x00, 0x00, 0x00, 0x00,
    0x00, 0x00, 0x00, 0x00, 0x00, 0x00, 0x18, 0x00, 0x01, 0x86, 0x00, 0x00,
    0x00, 0x00, 0x00, 0x00, 0x00, 0x00, 0x00, 0x00, 0x00, 0x00, 0x18, 0x00,
    0x01, 0x02, 0x00, 0x00, 0x00, 0x00, 0x00, 0x00, 0x00, 0x00, 0x00, 0x00,
    0x00, 0x00, 0x18, 0x00, 0x03, 0x06, 0x00, 0x00, 0x00, 0x00, 0x00, 0x00,
    0x00, 0x00, 0x00, 0x00, 0x00, 0x00, 0x08, 0x00, 0x03, 0x06, 0x00, 0x00,
    0x00, 0x00, 0x00, 0x00, 0x00, 0x00, 0x00, 0x00, 0x00, 0x00, 0x08, 0x00,
    0x03, 0x04, 0x00, 0x00, 0x00, 0x00, 0x00, 0x00, 0x00, 0x00, 0x00, 0x00,
    0x00, 0x00, 0x0c, 0x00, 0x07, 0x8c, 0x00, 0x00, 0x00, 0x00, 0x00, 0x00,
    0x00, 0x00, 0x00, 0x00, 0x00, 0x00, 0x04, 0x00, 0x06, 0xf8, 0x00, 0x00,
    0x00, 0x00, 0x00, 0x00, 0x00, 0x00, 0x00, 0x00, 0x00, 0x00, 0x06, 0x00,
    0x0c, 0x00, 0x00, 0x00, 0x00, 0x00, 0x00, 0x00, 0x00, 0x00, 0x00, 0x00,
    0x00, 0x00, 0x7f, 0xff, 0xff, 0xc0, 0x00, 0x00, 0x00, 0x00, 0x00, 0x00,
    0x00, 0x00, 0x00, 0x00, 0x00, 0x00, 0x7f, 0xff, 0xff, 0xc0, 0x00, 0x00,
    0x00, 0x00, 0x00, 0x00, 0x00, 0x00, 0x00, 0x00, 0x00, 0x00, 0x30, 0x00,
    0x01, 0x80, 0x00, 0x00, 0x00, 0x00, 0x00, 0x00, 0x00, 0x00, 0x00, 0x00,
    0x00, 0x00, 0x1c, 0x00, 0x07, 0x00, 0x00, 0x00, 0x00, 0x00, 0x00, 0x00,
    0x00, 0x00, 0x00, 0x00, 0x00, 0x00, 0x0f, 0xff, 0xfe, 0x00, 0x00, 0x00,
    0x00, 0x00, 0x00, 0x00, 0x00, 0x00, 0x00, 0x00, 0x00, 0x00, 0x00, 0xff,
    0xe0, 0x00, 0x00, 0x00, 0x00, 0x00, 0x00, 0x00, 0x00, 0x00, 0x00, 0x00,
    0x00, 0x00, 0x00, 0x00, 0x00, 0x00, 0x00, 0x00, 0x00, 0x00, 0x00, 0x00,
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

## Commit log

2021-03-01 Add schematic for pump control unit
    Adds schematic for the pump control unit. This will attach to a head unit via DB9, and the head unit hasn't yet been designed.
    [gaggia_mod_internal.kicad_pcb, gaggia_mod_internal.sch]
2021-03-02 Increase preinfuse pump time, clear display at start, fix temp probe
    [coffeetron.ino]
2021-03-03 Add rotary encoder
2021-03-03 Add busted encoder interrupt code
2021-03-04 [BROKEN] refactor into function pointers
    [coffeetron.ino]
2021-03-04 Fix bad state transition
    [coffeetron.ino]
2021-03-04 Make rotary encoder work and buttons work better
2021-03-04 Clamp inputs
2021-03-05 Add makefile and brew stats button
2021-03-06 Finish pump design
    [Omron_-_G3MC202PDC24.step, gaggia_mod_internal.kicad_pcb, gaggia_mod_internal.sch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]
2021-03-08 Add config for desired temperature
2021-03-08 PID control temp
2021-03-08 Rework pump hardware based on experimentation
    [pump.kicad_pcb, pump.sch]
2021-03-15 Switch to Teensy 4.0, move to Platformio
2021-03-16 Add head unit
    [head.kicad_pcb, head.sch]
2021-03-18 Add gerber files
    [head-B_Cu.gbr, head-B_Mask.gbr, head-B_SilkS.gbr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]
2021-03-18 Fix LED label
    [pump.kicad_pcb]
2021-03-18 Add label, adjust ground plane
    [pump.kicad_pcb]
2021-03-18 Fix ground plane
    [pump.kicad_pcb]
2021-04-07 Update head unit
    [head.kicad_pcb, head.sch]
2021-04-07 Move inductor
    [head.kicad_pcb]
2021-04-07 Reorder caps and resistors
    [head-B_Cu.gbr, head-B_Mask.gbr, head-B_Paste.gbr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]
2021-04-09 Vias for days
    [head.kicad_pcb, head.sch]
2021-04-10 Move silkscreen around
    [head.kicad_pcb]
2021-04-13 Remove unnecessary boost converter
    [head-B_Cu.gbr, head-B_Mask.gbr, head-B_Paste.gbr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]
